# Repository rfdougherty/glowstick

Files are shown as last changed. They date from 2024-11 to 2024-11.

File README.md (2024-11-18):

# glowstick

An 8-channel high power LED driver for light-art projects. This work was inspired by a [project](https://github.com/rfdougherty/ledFlicker) that I built many years ago to do visual experiments in an MRI scanner. Some [old python code from that work](https://github.com/vistalab/vistadisp/tree/master/ledFlicker/python) might be useful. E.g., here's [code](https://github.com/vistalab/vistadisp/blob/master/ledFlicker/python/ledFlickComputeXform.py) to compute human cone LMS stimulation from LED color power spectra.

<p align="center">
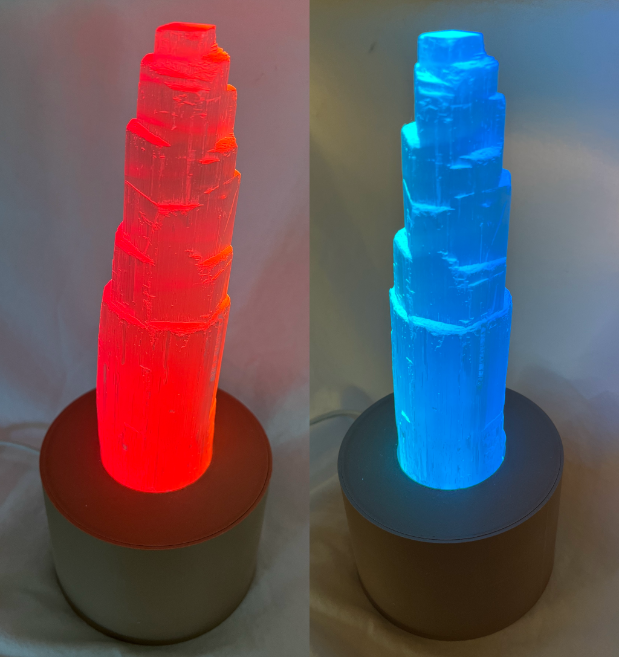
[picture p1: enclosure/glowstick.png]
Glowstick
  
</p>

## Hardware

The LED drivers use a simple [constant-current driver](https://www.instructables.com/Power-LED-s---simplest-light-with-constant-current/) with the LED current determined by a current-sense resistor Rcs. The LED current is approximately equal to 0.5 / Rcs and the power dissipated by the resistor is approximately 0.25 / Rcs. In the schematic here, I set Rcs to 0.75Ω to achieve an LED current of about 0.67A, safely under the 700mA rating for the [Luxeon Rebel LEDs](https://luxeonstar.com/wp-content/uploads/documentation/ds68.pdf) that I used. With this value, Rcs will dissipate up to 333mW, so be sure to use at least a 1/2W resistor. The MOSFETs will also dissipate some power, with the amount a function of the LED power and the voltage difference between the source supply and the LED forward voltage. E.g., if the LEDs are drawing 700mA at a Vf of 3V using a 5V supply, the MOSFETs will dissipate about 2*0.7=1.4W. At these levels, the MOSFETs will get quite hot and should be attached to a small heatsink. While not nearly as efficient as a buck driver, this driver circuit is simple, reliable, and cheap.

Note that to consistently drive the LEDs at or near 700mA you will also need adequate thermal management for the LED module. From the LuxeonStar site:
> A suitable finned heatsink or other cooling method must always be used with the SP-02 LED module to ensure that the junction temperature of the LEDs is kept well below the maximum rating specified in the Lumileds datasheet. The size of the heatsink will depend on the ambient temperature and the current used to power the LEDs. Bench testing that we have conducted with SP-02 modules powered at 700mA in an open-air environment and an ambient temperature of 25°C has indicated that a heat sink with a thermal rating of 9 C°/W or lower should be adequate.

The schematic and layout was designed in [EasyEDA](https://easyeda.com/) and the [EasyEDA json files](hardware/) are included. After getting the board made and testing it, I realized that I forgot to add pull-down resistors to keep the LEDs off when the microcontroller is not connected or is rebooting. For my build, I squeezed 10kΩ resistors in with the 1kΩ resistor leads and the ground end of the 0.75Ω resistor leads. But it would be best to update the schematic to include these pull-downs.

<div style="display: flex; gap: 20px;">
    Schematic
    Layout
</div>

The circuit includes a voltage regulator so a microcontroller can be powered by the LED supply. If you use a 5V supply and your microcontroller has a 5V input, then you can omit the voltage regulator and just add a bypass wire. Or, you could populate it with a 3.3V regulator if your input supply is less than 5V but greater than 3.3V. Also, as noted above, the power dissipation of the MOSFETs is affected by the voltage difference between the source supply and the LED forward voltage. So you could make it more efficient by using a supply that is closer to the maximum LED forward voltage. Just be sure to account for the 0.5V dropout in the circuit. E.g., if you are using LEDs with a Vf of no more than 3.2V, then you could use a 3.7V supply to get the best efficiency.

I used a [Wemos S3 Mini](https://www.wemos.cc/en/latest/s3/s3_mini.html) for the microcontroller.

## Firmware

The firmware is written in C/C++ using [Arduino](https://www.arduino.cc/) and the [aWOT framework](https://github.com/rbaron/aWOT). Note that I used a 7-LED module for my build, so the firmware currently only supports 7 channels. If you do use the 8th channel, you will need to update the firmware.

The code runs a web server with the following API endpoints:

- `GET /config` - Retrieve the current configuration as JSON
- `POST /config` - Update the configuration (expects JSON payload)
- `GET /leds` - Get the current LED PWM values for all 7 channels
- `PUT /leds/:l0/:l1/:l2/:l3/:l4/:l5/:l6` - Set the LED PWM values (0-1023 for each channel)
- `PUT /iscale/:scale` - Set the intensity scale (0.0-1.0)
- `PUT /mod/:amp/:step` - Set modulation parameters (amplitude and step, 0.0-1.0)
- `PUT /update/:interval` - Set update interval (10-9999999 microseconds)
- `GET /sensors` - Get sensor data (temperature, time, LED states)
- `GET /reboot` - Trigger system reboot

TODO:
- Add a web GUI to allow easy configuration
- MQTT support
- Add timer functions, including sunrise/sunset support
- Add LED spectra (measured or from the datasheet) and allow HSV color control

## Enclosure

An [enclosure](enclosure/) for the pcb, microcontroller module, and a 7-chip [LuxeonStar](https://luxeonstar.com/) LED module was designed in [OpenSCAD](https://www.openscad.org/). The seven [Luxen Rebel](https://luxeonstar.com/wp-content/uploads/documentation/ds68.pdf) LEDs illuminate a large [selenite](https://en.wikipedia.org/wiki/Selenite_(mineral)) tower crystal. The LED module that I used had the following chips [custom-mounted to a 40mm round FR4 Coolbase board](https://luxeonstar.com/product/sp-02/):
 * Royal-Blue (LXML-PR02-A900)
 * Blue (LXML-PB02)
 * Cyan (LXML-PE01-0070)
 * Green (LXML-PM01-0100)
 * Lime (LXML-PX02-0000)
 * Amber (LXM5-PL01)
 * Deep Red (LXM3-PD01)

The LEDs were diffused with a [Polymer Optics 12° 39 mm Circular Beam Diffused Optic](https://luxeonstar.com/product/264/). A summary of the relevant specs (all driven at 350mA, except royal blue at 700mA) from the datasheet.
| Color | Flux/Power  | Vf (typ) | Wavelength |
|---|---|---|---|
| Royal-Blue | 940 mW | 2.9V  | 440-460 nm |
| Blue | 41 lm | 2.95V | 460-485 nm |
| Cyan | 76 lm | 3.17V | 490-515 nm |
| Green | 102 lm | 3.21V | 520-540 nm |
| Lime | 184 lm | 2.75V | 566-569 nm |
| Amber | 99 lm | 2.1V  | 585-595 nm |
| Deep Red | 360 mw | 2.1V  | 650-670 nm |

## Measurements
The MOSFETs used in this build are the most temperature critical parts, as you can easily fry them with a good thermal design. The IRL2703 MOSFETs that I used have a junction-to-case thermal resistance of 3.3 W/°C and maximum junction temperature of 175°C, the [maximim safe case temerature](https://community.infineon.com/t5/Knowledge-Base-Articles/Calculating-the-case-temperature-Tc-of-MOSFET-and-controller-in-CCG7DC/ta-p/401569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.) is 170°C for the Vf 2.1V LEDs driven at 700mA. That's pretty toasty, so I try to keep it under 100°C. 

To test the safe operating range, I first measured everything in open-air (room temp ~20°C) with no heatsinks at a 25% PWM duty cycle (LED PWM value of 256) and noted that the peak board temperature (ie, MOSFET case temp) was under 55°C. 

I made individual LED measurements at a 50% duty cycle (LED value of 512), and observed the following temperatures after about 5 minutes (that's when temps seem to asymptote). At this duty cycle, the total system curent draw was about 300 mA for one LED.

| Color | Vf (typ) | Temp |
|---|---|---|
| Royal-Blue | 2.9V | 42°C |
| Blue | 2.95V | 42°C |
| Cyan | 3.17V | 41°C |
| Green | 3.21V | 42°C |
| Lime | 2.75V | 43°C |
| Amber | 2.1V | 65°C |
| Deep Red | 2.1V | 62°C |

With small stick-on heatsinks (~5x5x4mm), I tested running all 7 LEDs at 50% duty cycle. This drew a total of about 1.6A and resulted in the following thermals for the board (left) and LED module (right):

<div style="display: flex; gap: 20px;">
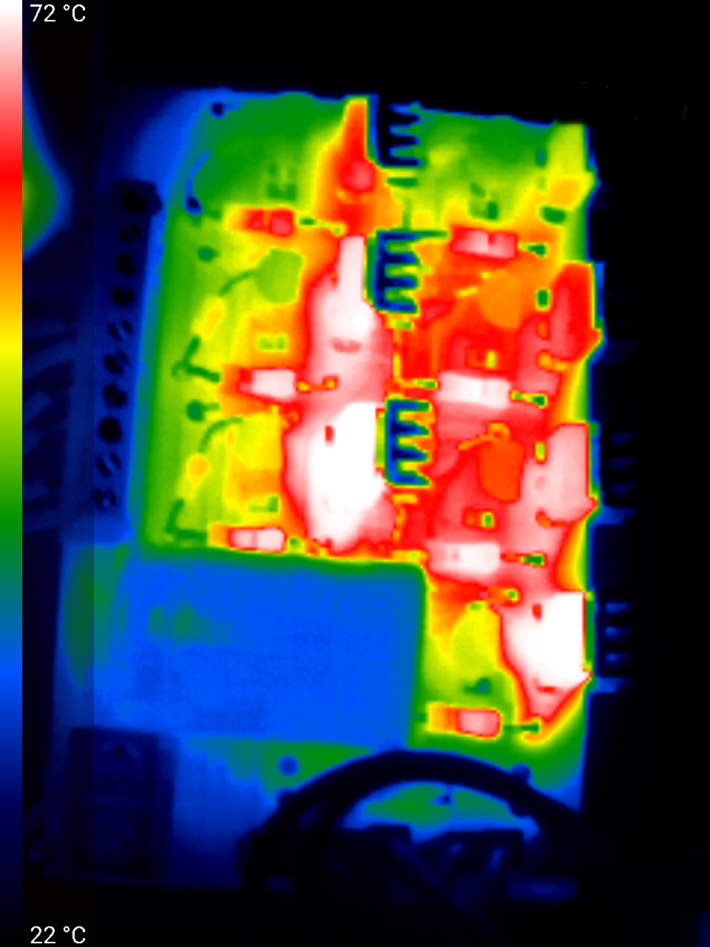
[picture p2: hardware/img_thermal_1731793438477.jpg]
Board thermal image
    
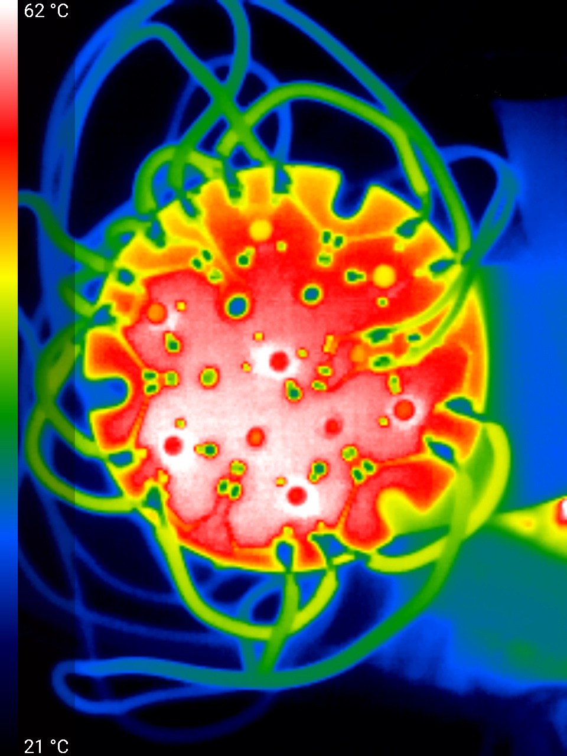
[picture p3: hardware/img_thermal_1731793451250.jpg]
LED board thermal image
    
</div>

With further testing with the small heatsinks on the MOSFETs, I would be comfortable driving all the LEDs except Amber and Deep Red at 100% duty cycle and keep the Amber and Deep Red at 75% or less and only drive them higher for brief periods of time. I'd also avoid driving lime at 100%. I will try using larger heatsinks and revisit these limits. For the LED module, you could get away not using a heatsink if only driving a couple of LEDs at full power for long periods of time. But your LEDs will be happier to be keep cooler with a modest heatsink.

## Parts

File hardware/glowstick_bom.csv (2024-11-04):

ID | Name | Designator | Footprint | Quantity | Manufacturer Part | Manufacturer | Supplier | Supplier Part | Price
1 | 100uF | C1 | CAP-TH_L3.8-W3.8-P2.54-D0.5 | 1
2 | 10uF | C2 | CAP-TH_L3.8-W3.8-P2.54-D0.5 | 1
3 | 1u | C3 | CAP-D10.0×F5.0 | 1
4 | PWM in | H1 | HDR-F-2.54_1X10 | 1 |  |  | LCSC | C35445 | 0.103
5 | IRL2703 | Q1,Q3,Q5,Q7,Q9,Q11,Q13,Q15 | TO-220-3_L9.9-W4.5-P2.54-L-1 | 8 | IRF5210STRLPBF | IR | LCSC | C2622 | 1.013
6 | 7905(TO-252) | U1 | PG-TO220-3_L10.0-W4.5-P2.54-L | 1 | CJ7905 | CJ | LCSC | C78860 | 0.254
7 | 1k | R1,R3,R5,R7,R9,R11,R13,R15 | RD-3.2X1.8-1/8W | 8
8 | 0.75Ω | R2,R4,R6,R8,R10,R12,R14,R16 | AXIAL-6.5X2.3(1/2WS) | 8
9 | HDR-F-2.54_1x10 | H2 | HDR-F-2.54_1X10 | 1 |  |  | LCSC | C35445 | 0.103
10 | 2N5088 | Q2,Q4,Q6,Q8,Q10,Q12,Q14,Q16 | S8050D | 8 | 2N3904 | SEMTECH | LCSC | C118538 | 0.016
11 | Vin | H3 | MORS_2P | 1 |  |  | Digi-Key | 1729128

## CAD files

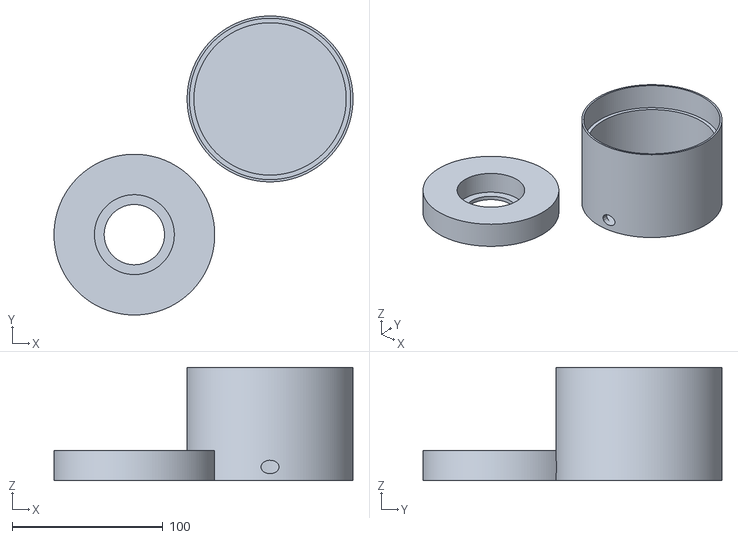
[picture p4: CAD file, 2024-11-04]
enclosure/glowstick_enclosure.stl
198.3 x 198.3 x 75.0

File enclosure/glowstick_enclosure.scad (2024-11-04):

$fa = 1;
base_height = 75;
base_diameter = 110;
top_height = 20;
thick = 3;
led_diam = 40;
crystal_diam = 53;
wire_diam = 12;
gap = 0.2; // clearance between insert and bore.
inset = 3.0;

translate([base_diameter/2-15, base_diameter/2-15, 0]){
  difference(){
    // Hull
    translate([0, 0, base_height/2])
      cylinder(h=base_height, r=base_diameter/2, center=true);
    // bottom cut-out
    translate([0, 0, base_height/2+thick + 0.1])
      cylinder(h=base_height-thick, r=base_diameter/2-thick/2-inset, center=true);
    // Top cut-out
    translate([0, 0, base_height-top_height/2+1])
      cylinder(h=top_height+2, r=base_diameter/2-thick/2, center=true);

    // Wire hole
    translate([0, -base_diameter/2+thick*2, thick+wire_diam/2])
      rotate([90, 0, 0])
        scale([1, 0.75, 1])
          cylinder(h=thick*4, r=wire_diam/2);
  }
}

// Top
translate([-base_diameter/2+5, -base_diameter/2+5, 0]){
  union(){
    difference(){
      translate([0, 0, top_height/2])
        cylinder(h=top_height, r=base_diameter/2-thick/2-gap, center=true);
      translate([0, 0, top_height/2+thick/2+0.01])
        cylinder(h=top_height-thick, r=crystal_diam/2, center=true);
      translate([0, 0, thick/2-0.01])
        cylinder(h=thick+0.1, r=led_diam/2, center=true);
    }
  }
}

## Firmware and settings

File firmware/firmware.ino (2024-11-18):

/*

Built for the LOLIN S3 MINI

For analog pin info, see page 16 of the s3 datasheet: 
https://www.espressif.com/sites/default/files/documentation/esp32-s3_datasheet_en.pdf

cyan, red, royal blue, blue, yellow, green, amber
thermistor is on pin 10 (3.3v ref)

@1kHz, each tick is 1ms

curl -X GET 'http://192.168.0.137/config'
curl -X POST  -H "Accept: application/json" -H "Content-Type: application/json" 'http://192.168.0.137/config' \
-d '{"play":[{"ticks":3000,"pwm":[50,0,0,0,0,0,0]},{"ticks":3000,"pwm":[0,50,0,0,0,0,0]}]}'
curl -X POST -H "Accept: application/json" -H "Content-Type: application/json" 'http://192.168.0.137/config' -d '{"iscale":0.9}'
*/

#include <Arduino.h>
#include "ConfigJson.h"
#include <WiFi.h>
#include <WiFiManager.h> //https://github.com/tzapu/WiFiManager WiFi Configuration Magic
#include <ESPmDNS.h>
#include <ArduinoOTA.h>
#include <Streaming.h>
#include <time.h>
#include <sunset.h>
#include "aWOT.h"
#include "StaticFiles.h"
//#include <AHTxx.h>
#define ARDUINOJSON_USE_DOUBLE 0
#include <ArduinoJson.h>

#define VERSION_STRING "glowstick 0.1"

// LED config
const uint8_t g_led_pins[] = {37,5,6,7,8,9,33};

const uint16_t PWM_FREQ = 500;
const uint8_t PWM_BITS = 10;
const uint16_t PWM_MAX = 1023;

// ADC2 is used by the wifi, so be sure to use an adc1 pin (1,2,3,4,5,6,7,8,9,10,14)
#define TEMP_SENSE_PIN 10

// AHTxx is i2c. Pin 35 is SDA and pin 36 is SCL on the lolin 23 mini.
//AHTxx aht10(AHTXX_ADDRESS_X38, AHT1x_SENSOR); //sensor address, sensor type

// getLocalTime is called often, so reduce the default timeout from 5s to .5s
#define TIME_SYNC_TIMEOUT_MS 500
struct tm g_timeinfo;

// Set up the led timeseries array. Currently hard-coded, but can be made configurable.
const uint16_t g_num_frames = 10;
FRAME g_leds[g_num_frames];
FRAME g_cur_led;
ConfigJson g_config("/config.json");

SunSet sun;

bool isNightOn = false;
float g_sunrise_mpm = 0;
float g_sunset_mpm = 0;
float g_cur_mpm;

//float g_temperature;
//float g_humidity;
uint32_t g_temp_mv;
char g_buf[500];

WiFiServer server(80);
Application app;
 
void setup(){
  // disable brownout detector (needed for one of the esp32 boards)
  //WRITE_PERI_REG(RTC_CNTL_BROWN_OUT_REG, 0);

  Serial.begin(115200);
  delay(100);
  Serial << F("Booting ") << VERSION_STRING << endl;
  delay(1000);

  // Set up LED PWMs
  for(uint8_t i; i<7; i++)
    ledcAttach(g_led_pins[i], PWM_FREQ, PWM_BITS);

  WiFiManager wifiManager;
  wifiManager.autoConnect("glowstick");
  Serial.println(WiFi.localIP());
  initApi();
  server.begin();

  g_config.start_fs();
  g_config.load_from_file();
  Serial << F("Configuring leds...") << endl;
  for (uint8_t i; i<7; i++) ledcWrite(i, g_config.led_init.raw[i]);

  sprintf(g_buf, "%s.local", g_config.hostname);
  MDNS.begin(g_buf);
  MDNS.addService("http", "tcp", 80);

  Serial.println(F("Configuring time..."));
  initTime();
  Serial.println("Starting OTA...");
  startOTA();

  // if(aht10.begin() != true) {
  //   Serial << F("AHT10 sensor failed to start!") << F("\n");
  // } else {
  //   g_temperature = aht10.readTemperature(); // read 6-bytes via I2C, takes 80 milliseconds
  //   g_humidity = aht10.readHumidity(AHTXX_USE_READ_DATA);
  //   Serial << F("AHT10 sensor initialized; temp=") << g_temperature << F("C, hum=") << g_humidity << F("%\n");
  // }
}


void loop() {
  static int curday = 32;
  static bool curdst = true;
  static uint32_t last_update = 0;
  static uint32_t last_mod_update = 0;

  uint32_t cur_us = micros();
  ArduinoOTA.handle();
  WiFiClient client = server.available();

  if (client.connected()) {
    app.process(&client);
  }

  // Update the sunset state, if needed
  if (curdst != g_timeinfo.tm_isdst || curday != g_timeinfo.tm_mday) {
    sun.setTZOffset(getUtcOffset());
    curdst = g_timeinfo.tm_isdst;
    sun.setCurrentDate(g_timeinfo.tm_year+1900, g_timeinfo.tm_mon+1, g_timeinfo.tm_mday);
    curday = g_timeinfo.tm_mday;
    g_sunrise_mpm = sun.calcSunrise();
    g_sunset_mpm = sun.calcSunset();
  }

  // Check temp every 3 sec
  if(cur_us - last_update >= 3000000) {
    //g_temperature = aht10.readTemperature(); // read 6-bytes via I2C, takes 80 milliseconds
    //g_humidity = aht10.readHumidity(AHTXX_USE_READ_DATA);
    g_temp_mv = analogReadMilliVolts(TEMP_SENSE_PIN);
    last_update = cur_us;
  }

  // Set LED PWM 
  if(cur_us - last_mod_update >= g_config.update_us) {
    for (uint8_t i; i<7; i++) {
      float val = g_config.iscale * g_cur_led.raw[i];
      if (val < 0.5) {
        ledcWrite(g_led_pins[i], 0);
        continue;
      }
      val += getRandomModulation(g_config.mod_amp, g_config.mod_step, i); //random(-g_mod * val, g_mod * val + 0.5);
      ledcWrite(g_led_pins[i], (uint32_t)constrain(round(val), 0, PWM_MAX));
    }
    last_mod_update = cur_us;
  }
  
  yield();
}

// Random-walk modulation
float getRandomModulation(float mod, float step, uint8_t i) {
    static float offsets[7] = {0,0,0,0,0,0,0};
    static float prev_mod = 0;
    if(mod != prev_mod)
      offsets[i] = 0;
    offsets[i] += constrain(random(-step*1000, step*1000 + 1) / 1000.0, -mod, mod);
    return offsets[i];
}

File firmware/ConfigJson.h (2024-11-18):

#pragma once

#ifndef ConfigJson_h
#define ConfigJson_h

#include "FS.h"
#include "SPIFFS.h"
#define MYFS SPIFFS
//#include <LittleFS.h>
//#define MYFS LittleFS
#define ARDUINOJSON_USE_DOUBLE 0
#include <ArduinoJson.h>
#include <Streaming.h>

struct FRAME  {
	union {
		struct {
      uint16_t l0;
      uint16_t l1;
      uint16_t l2;
      uint16_t l3;
      uint16_t l4;
      uint16_t l5;
      uint16_t l6;
		};
		uint16_t raw[7];
	};
	FRAME(){}
	FRAME(uint16_t n0, uint16_t n1, uint16_t n2, uint16_t n3, uint16_t n4, uint16_t n5, uint16_t n6){
		l0 = n0;
		l1 = n1;
		l2 = n2;
		l3 = n3;
		l4 = n4;
		l5 = n5;
		l6 = n6;
	}
};

class ConfigJson {
  public:
    float iscale;
    float mod_amp;
    float mod_step;
    uint32_t update_us;
    uint16_t temp_max;
    FRAME led_init;
    float latitude;
    float longitude;
    char ntp_server[32];
    char timezone[32];
    char hostname[32];

    ConfigJson(const char *path) {
      file_name = path;
    }

    void start_fs() {
      Serial.println(F("Starting FS..."));
      if (!MYFS.begin(true)) {
        Serial.println(F("ERROR: file system failed to start"));
      }
    }

    bool load_from_file() {
      set_defaults();
      if (!MYFS.exists(file_name)) {
        Serial.println(F("Config file does not exist; using defaults and saving."));
        save_to_file();
        return true;
      }
      File fp = MYFS.open(file_name, "r");
      if (!fp) {
        Serial << F("Reading config file ") << file_name << F("failed.") << F("\n");
        fp.close();
        return false;
      }
      // Allocate a temporary JsonDocument and deserialize
      JsonDocument doc;
      DeserializationError error = deserializeJson(doc, fp);
      if (error) {
        Serial.println(F("Failed to read file, using default configuration"));
        fp.close();
        return false;
      }
      doc_to_config(doc);      
      fp.close();
      Serial << F("Read config from file ") << file_name << F(".\n");
      return true;
    }

    void load_from_doc(JsonDocument doc) {
      doc_to_config(doc);
    }

    bool save_to_file() {
      if (!MYFS.begin()) {
        Serial.println("ERROR: file system failed to start");
        return false;
      }
      File fp = MYFS.open(file_name, "w");
      if (!fp) {
        Serial.println(F("Failed to create config file"));
        return false;
      }
      JsonDocument doc = config_to_doc();
      if (serializeJson(doc, fp) == 0) {
        Serial.println(F("Failed to write config to file"));
        fp.close();
        return false;
      }
      fp.close();
      Serial << F("Config file") << file_name << F(" saved.\n");
      Serial.println(doc["hostname"].as<const char*>());
      return true;
    }

    bool save_to_buffer(char buf[], uint16_t bufsz) {
      JsonDocument doc = config_to_doc();
      Serial.println(doc["ntp_server"].as<const char*>());
      int n_char = serializeJson(doc, buf, bufsz);
      return n_char;
    }

  private:
    const char *file_name;

    void set_defaults() {
      iscale = 1.0; // 0-1, applies a global intenstiry scale factor to LED PWM values
      mod_amp = 0.0; // 0-1, random modulation proportion
      mod_step = 0.0; // 0-1, random modulation step size proportion
      update_us = 2000;
      temp_max = 5000; // millivolts, turn off all leds if temp mv is >= this
      for (uint8_t i; i<7; i++) led_init.raw[i] = 0;
      latitude = 37.47889776969171;
      longitude = -122.24059783307233;
      strlcpy(ntp_server, "pool.ntp.org", sizeof(ntp_server));
      strlcpy(timezone, "PST8PDT,M3.2.0,M11.1.0", sizeof(timezone));
      strlcpy(hostname, "glowstick", sizeof(hostname));
    }

    void doc_to_config(JsonDocument doc) {
      if(doc["iscale"] != nullptr) iscale = doc["iscale"];
      if(doc["mod_amp"] != nullptr) mod_amp = doc["mod_amp"];
      if(doc["mod_step"] != nullptr) mod_step = doc["mod_step"];
      if(doc["upate_us"] != nullptr) update_us = doc["update_us"];
      if(doc["temp_max"] != nullptr) temp_max = doc["temp_max"];
      JsonArray arr = doc[F("led_init")];
      if(arr) for (uint8_t i; i<7; i++) led_init.raw[i] = arr[i];
      //arr = doc[F("minute_rgbw")];
      //if(arr) min_rgbw = CRGBW(arr[0], arr[1], arr[2], arr[3]);
      if(doc["latitude"] != nullptr) latitude = doc["latitude"];
      if(doc["longitude"] != nullptr) longitude = doc["longitude"];
      if(doc["ntp_server"]) strlcpy(ntp_server, doc["ntp_server"], sizeof(ntp_server));
      if(doc["timezone"]) strlcpy(timezone, doc["timezone"], sizeof(timezone));
      if(doc["hostname"]) strlcpy(hostname, doc["hostname"], sizeof(hostname));
    }
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

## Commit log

2024-11-04 Initial commit of this 2 year-old project
    [glowstick_bom.csv, glowstick_enclosure.scad, glowstick_enclosure.stl]
2024-11-04 Fix enclosure link
